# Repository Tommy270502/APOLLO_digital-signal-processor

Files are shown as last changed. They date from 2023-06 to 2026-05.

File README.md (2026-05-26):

# APOLLO Digital Signal Processor

APOLLO is a USB-powered STM32F401 digital signal-processing board and firmware
case study. The repository combines KiCad hardware design, STM32CubeIDE
firmware, external analog and memory devices, host-side tests for reusable C
logic, and validation notes for hardware-dependent behavior.

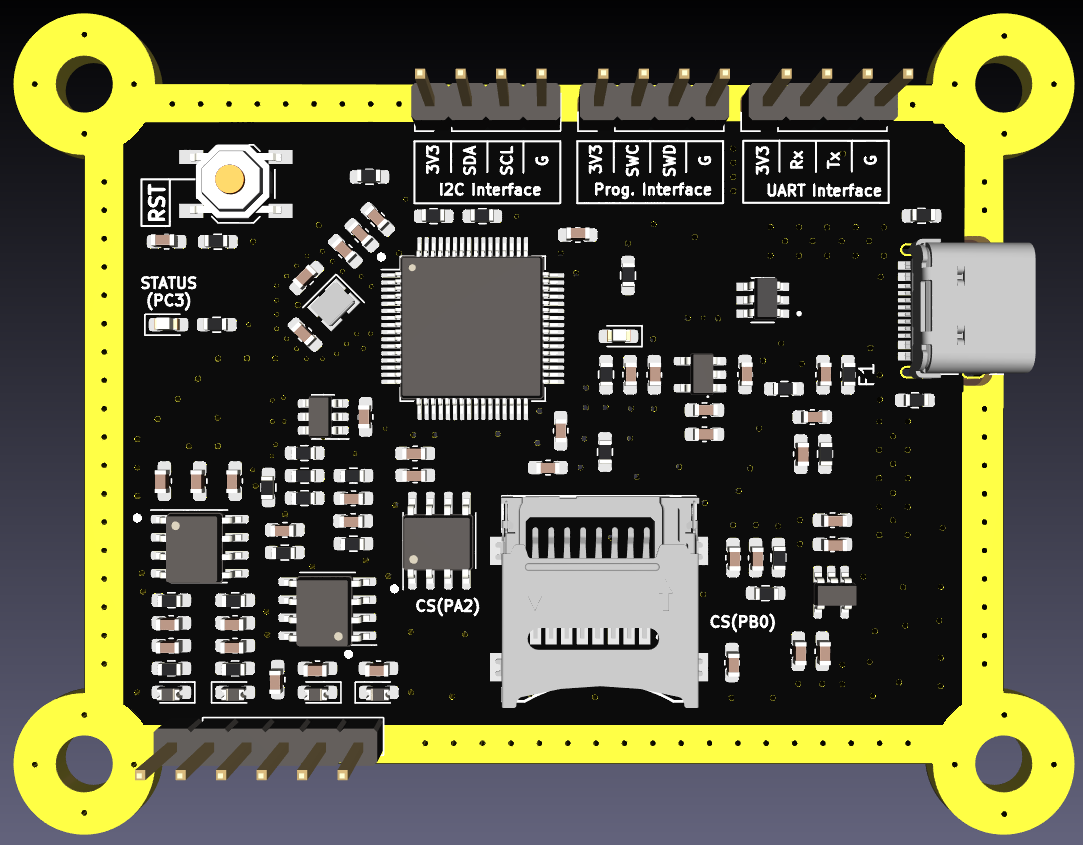
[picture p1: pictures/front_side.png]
APOLLO front side

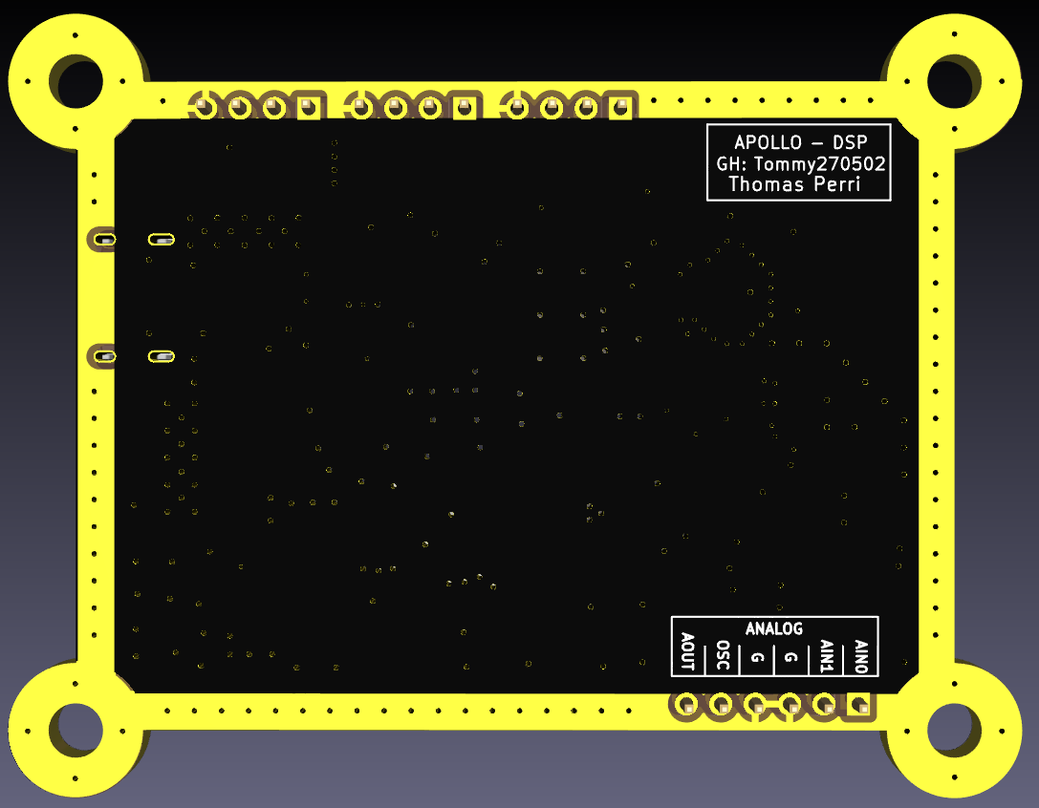
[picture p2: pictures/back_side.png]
APOLLO back side


## What This Demonstrates

- STM32F401 firmware architecture with CubeMX-generated code kept separate from
  hand-written application logic.
- USB CDC command and telemetry interface for live DSP configuration.
- Two-channel analog input support, external I2C DAC output, and SPI SRAM
  circular sample logging.
- Embedded-friendly DSP filters with fixed buffers and parameter validation.
- Clear distinction between implemented, host-tested, and hardware-validation
  required features.

## System Overview

```mermaid
flowchart LR
    Host["PC serial monitor"] <-- "USB CDC" --> USB["USB-C + ESD"]
    USB --> MCU["STM32F401RBTx\n84 MHz Cortex-M4F"]
    AIN["AIN0 / AIN1"] --> Analog["MCP602 analog conditioning"]
    Analog --> ADC["ADC1 CH0 / CH1"]
    ADC --> MCU
    MCU -- "I2C1 PB6/PB7" --> DAC["MCP4725-family\n12-bit I2C DAC"]
    DAC --> AOUT["Analog output"]
    MCU -- "SPI1 PA5/PA6/PA7" --> SRAM["23K256\n32 KiB SPI SRAM"]
    MCU -- "SPI1 + SD_nCS" --> SD["microSD socket\nfirmware unsupported"]
    MCU --> SWD["SWD debug"]
    MCU --> UART["USART1 header"]
```

## Firmware Architecture

```mermaid
flowchart TD
    Main["main.c\nHAL + CubeMX init"] --> App["app/apollo_app"]
    App --> ADC["platform/apollo_adc\nbounded polling"]
    App --> USB["platform/apollo_usb_cdc\nRX line buffer + TX wrapper"]
    App --> Chain["app/apollo_signal_chain"]
    Chain --> DSP["dsp/dsp_filters"]
    App --> DAC["drivers/dac_driver"]
    App --> Store["app/apollo_storage"]
    Store --> SRAM["drivers/sram_23k256"]
    App --> Tel["app/apollo_telemetry"]
    App --> Diag["app/apollo_diagnostics"]
    App --> CLI["app/apollo_cli"]
```

`main.c` now performs HAL initialization, CubeMX peripheral initialization, and
then calls `apollo_app_init()` and `apollo_app_task()`. Application behavior is
kept under `Software/Apollo - DSP/Core/Inc/*` and
`Software/Apollo - DSP/Core/Src/*`.

## Signal Pipeline

```mermaid
flowchart LR
    Source{"Source"} -->|ADC CH0/CH1| Raw["raw ADC"]
    Source -->|demo mode| Raw
    Raw --> Cal["offset/gain calibration"]
    Cal --> Filter["runtime DSP filter"]
    Filter --> Clamp["DAC saturation handling"]
    Clamp --> DAC["I2C DAC write"]
    Filter --> Telemetry["USB CDC telemetry"]
    Clamp --> Log["SPI SRAM circular log"]
    Raw --> Diagnostics["min/max/mean/errors"]
```

Default firmware behavior preserves the original demo path: ADC channel 0 is
sampled, a 1 kHz first-order low-pass filter is applied, the result is written
to the external DAC, telemetry is streamed over USB CDC, and compact sample
records are written to external SRAM when the SRAM self-test passes.

## USB Commands

Commands are sent over the USB CDC virtual COM port with newline termination.

| Command | Purpose |
| --- | --- |
| `help` | Print command summary. |
| `status` | Print sample count, channel, filter, demo, calibration, storage, and error counters. |
| `filter bypass` | Disable filtering. |
| `filter lowpass <hz>` | First-order low-pass IIR. |
| `filter highpass <hz>` | First-order high-pass IIR. |
| `filter ema <alpha>` | Exponential moving average, `0 < alpha <= 1`. |
| `filter average <n>` | Moving average, up to 16 samples. |
| `filter median <n>` | Median filter, up to 9 samples. |
| `input 0` / `input 1` | Select ADC channel 0 or 1. |
| `demo off\|sine\|step\|impulse` | Use real ADC input or synthetic samples. |
| `telemetry on\|off` | Enable or disable periodic telemetry frames. |
| `calibrate clear` | Restore unity ADC/DAC scaling. |
| `calibrate adc <gain> <offset>` | Set ADC input calibration (gain 0.01-100, offset +/-4095). |
| `calibrate dac <gain> <offset>` | Set DAC output calibration (gain 0.01-100, offset +/-4095). |

## Telemetry

Sample frames use this CSV format:

```text
T,timestamp_ms,sequence,channel,raw_adc,filtered,dac_code,filter,flags
```

Example:

```text
T,1200,57,0,1820,1784.42,1784,lowpass,0x00000000
```

Flags report clipping, demo source, filter errors, ADC errors, DAC errors, and
SRAM logging errors.

## Repository Layout

| Path | Purpose |
| --- | --- |
| `Apollo - DSP.kicad_pro` | Main KiCad project. |
| `Apollo - DSP.kicad_sch`, `Analog.kicad_sch`, `DSP.kicad_sch` | Hardware schematics. |
| `Apollo - DSP.kicad_pcb` | PCB layout. |
| `Gerber/` | Fabrication outputs. |
| `pictures/` | Board images. |
| `datasheets/` | Local component datasheets. |
| `Software/Apollo - DSP/` | STM32CubeIDE firmware project. |
| `tests/host/` | Host-buildable tests for pure C logic. |
| `docs/` | Technical documentation and validation notes. |

See [REPOSITORY_STRUCTURE.md](REPOSITORY_STRUCTURE.md) for more detail.

## Build And Flash

1. Open STM32CubeIDE.
2. Import `Software/Apollo - DSP/` as an existing STM32CubeIDE project.
3. Build the Debug or Release configuration.
4. Flash/debug over the SWD header using an ST-LINK compatible probe.
5. Open the USB CDC virtual COM port with a serial terminal.
6. Send `help`, `status`, or `demo sine` to verify the command path.

Generated `Debug/` and `Release/` folders are intentionally not tracked.
STM32CubeIDE regenerates them locally.

## Host Tests

Host tests cover pure logic that does not require STM32 HAL or board hardware:

```sh
make -C tests/host test
```

The tests exercise DSP filter behavior, command parsing, telemetry formatting,
diagnostics, calibration/clipping math, and signal-chain demo paths.

## Validation Status

- Host tests pass on Windows 11 / MSYS2 / GCC 15.2.0 (2026-05-27).
- Firmware Debug and Release builds pass with 0 errors (STM32CubeIDE 2.0.0,
  arm-none-eabi-gcc 14.3.1, 2026-05-27).
- Hardware-dependent behavior requires board validation:
  ADC channel accuracy, DAC output voltage, SRAM SPI timing, and USB behavior
  under sustained traffic.
- microSD hardware is present, but firmware support is explicitly unsupported
  until a real SPI block-device and filesystem implementation is added.

See [docs/validation.md](docs/validation.md) for the full validation checklist.

## Engineering Highlights

- CubeMX-generated code is preserved and hand-written application code is moved
  into reviewable modules.
- Peripheral failures no longer force infinite retry loops in application code.
- Runtime filter selection and demo sources make the board demonstrable without
  external analog equipment.
- Documentation states validation limits instead of claiming untested hardware
  support.

## Future Work

- Move ADC acquisition to timer-triggered DMA with overrun accounting.
- Add real microSD support using a validated SPI block-device layer and FatFs.
- Add fixture-based hardware tests for DAC linearity, ADC channel calibration,
  SRAM retention, and USB throughput.
- Add optional firmware CI if a reproducible STM32 toolchain image is adopted.

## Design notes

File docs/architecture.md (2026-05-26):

# Architecture

APOLLO separates generated STM32CubeIDE infrastructure from hand-written
application firmware. CubeMX owns peripheral setup in `main.c`, MSP files, USB
device glue, HAL, CMSIS, and middleware. Application code lives below
`Core/Inc/app`, `Core/Inc/dsp`, `Core/Inc/drivers`, and `Core/Inc/platform`
with matching source folders.

```mermaid
flowchart TD
    Main["CubeMX main.c"] --> App["apollo_app"]
    App --> Platform["platform\nADC + USB CDC helpers"]
    App --> Signal["signal chain"]
    Signal --> DSP["DSP filters"]
    App --> Drivers["DAC + SRAM + SD status drivers"]
    App --> Telemetry["telemetry formatter"]
    App --> Diagnostics["diagnostics counters"]
    App --> CLI["command parser"]
```

The main runtime path is tick scheduled. ADC polling is still used in this
cleanup pass, but it is bounded and isolated in `platform/apollo_adc.c` so a
future timer/DMA implementation can replace it without rewriting the signal
chain.

## Data Flow

```mermaid
flowchart LR
    ADC["ADC or demo source"] --> Process["calibrate + filter"]
    Process --> DAC["DAC code clamp"]
    DAC --> I2C["I2C DAC write"]
    Process --> USB["CSV telemetry"]
    DAC --> SRAM["8-byte SRAM record"]
    Process --> Diag["diagnostics"]
```

The SRAM record format is little-endian:

| Offset | Type | Field |
| --- | --- | --- |
| 0 | `uint32_t` | timestamp in milliseconds |
| 4 | `uint16_t` | raw ADC code |
| 6 | `uint16_t` | DAC code |

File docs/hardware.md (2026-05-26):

# Hardware

APOLLO is a USB-powered STM32F401RBTx board with analog input/output circuitry,
external SRAM, USB CDC connectivity, and debug headers.

## Main Blocks

- STM32F401RBTx MCU running from an HSE-based 84 MHz clock configuration.
- USB-C connector with USB OTG FS routed to PA11/PA12.
- Two analog input labels, `AIN0` and `AIN1`, routed through analog conditioning
  to ADC channel nets.
- MCP4725-family external I2C DAC on I2C1.
- 23K256 32 KiB SPI SRAM on SPI1.
- microSD socket sharing the SPI bus through a separate chip-select net.
- SWD and USART1 headers for programming, debug, and expansion.

## DAC Naming

The schematic uses an MCP4725-family KiCad symbol. The firmware now uses a
neutral `dac_driver` name and documents the driver as MCP4725-family compatible
instead of naming the source files after MCP4726.

## SD-Card Status

The microSD socket is present in hardware. Firmware support is intentionally
reported as unsupported until an SPI block-device layer, card initialization,
and filesystem integration are implemented and validated.

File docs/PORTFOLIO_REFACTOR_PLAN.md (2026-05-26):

# APOLLO Portfolio Refactor Plan

## Summary

This plan turns APOLLO from a functional project archive into a public embedded
engineering case study. The work is split into small phases so each change can
be reviewed independently and validated at the right level.

## Phase 1: Repository Hygiene

- Remove tracked generated artifacts and local state:
  - STM32CubeIDE workspace metadata in `Software/.metadata/`
  - Generated firmware build outputs in `Software/Apollo - DSP/Debug/` and
    `Software/Apollo - DSP/Release/`
  - KiCad lock/cache/local files and automatic backup ZIPs
  - Packaged ZIP snapshots
  - Broken or unsupported local artifacts such as the orphaned KiCad plugin
    gitlink and stale unused flash header
- Keep source assets needed to understand, build, fabricate, or validate the
  project:
  - KiCad schematics, PCB, project files, Gerbers, board pictures, datasheets
  - STM32CubeIDE project files, CubeMX `.ioc`, linker script, startup, HAL,
    CMSIS, USB middleware, and hand-written firmware source
- Strengthen `.gitignore` for STM32CubeIDE, KiCad, generated binaries,
  archives, temporary files, and local metadata.
- Add a short repository structure document.

## Phase 2: Firmware Architecture Cleanup

- Keep CubeMX generated code boundaries intact.
- Add clear hand-written firmware folders:
  - `Core/Inc/app` and `Core/Src/app`
  - `Core/Inc/dsp` and `Core/Src/dsp`
  - `Core/Inc/drivers` and `Core/Src/drivers`
  - `Core/Inc/platform` and `Core/Src/platform`
- Refactor `main.c` so it mainly performs HAL setup, CubeMX peripheral setup,
  application initialization, and the application run loop.
- Move application behavior into focused modules for configuration, signal
  processing, telemetry, diagnostics, storage, and platform access.

## Phase 3: DSP Feature Enhancement

- Replace the minimal filter module with a reusable embedded DSP filter library.
- Implement fixed-size, no-allocation filters:
  - bypass
  - first-order low-pass IIR
  - first-order high-pass IIR
  - exponential moving average
  - moving average
  - small-window median
- Validate parameters and expose reset/init/update APIs.
- Add a minimal command parser for runtime filter selection where practical.

## Phase 4: Signal-Chain Improvements

- Preserve the current default behavior while making the signal chain explicit.
- Add active ADC channel selection between the two wired analog inputs.
- Add calibration, clipping/saturation flags, diagnostics, and a synthetic demo
  source.
- Expand telemetry to include timestamp, sequence, channel, raw ADC, filtered
  value, DAC code, filter mode, and flags.
- Document SRAM circular logging format.

## Phase 5: ADC and Timing Review

- Isolate ADC acquisition behind a platform module.
- Replace unbounded ADC waits and delay-driven timing with bounded polling and
  tick-based scheduling in this cleanup pass.
- Document timer/DMA sampling as a future upgrade unless it is implemented and
  hardware-validated later.

## Phase 6: Driver Cleanup

- Improve external SRAM and DAC APIs with status returns and input validation.
- Rename or document the external DAC driver using neutral MCP4725-family
  naming.
- Keep USB CDC telemetry nonblocking where possible and account for busy states.
- Replace SD-card no-op stubs with an honest unsupported status.

## Phase 7: Tests and Host-Side Validation

- Add a lightweight host-buildable C test runner.
- Cover DSP filters, command parsing, telemetry formatting, calibration math,
  and circular-buffer indexing.
- Use plain `gcc` and `make` instead of a heavy test framework.

## Phase 8: Documentation

- Upgrade README into a concise public case study.
- Add focused technical docs:
  - architecture
  - firmware
  - DSP filters
  - demo usage
  - hardware
  - testing
  - validation
  - future work
- Use Mermaid diagrams for architecture, data flow, and state-machine views.

## Phase 9: CI and Automation

- Add GitHub Actions for host-side tests and lightweight documentation/repo
  sanity checks.
- Document manual STM32CubeIDE build and flash steps instead of pretending
  firmware CI exists if the embedded toolchain is not installed in CI.

## Phase 10: Portfolio Polish

- Add engineering highlights, design tradeoffs, validation limits, and future
  work sections.
- Make the final repository credible to embedded hardware, firmware, and
  systems-integration reviewers.

## Validation Strategy

- Use narrow checks first:
  - `git status --short`
  - tracked-file audits for generated artifacts
  - host tests once added
  - local firmware build if the STM32 toolchain is available
- Document hardware-only validation steps when hardware cannot be exercised
  directly.

## Assumptions

- Hardware validation is not available during this cleanup pass.
- CubeMX regeneration safety is more important than aggressive code movement.
- Unsupported hardware functions should be documented honestly rather than
  represented as working firmware features.

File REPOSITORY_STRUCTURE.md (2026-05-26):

# Repository Structure

APOLLO is organized so hardware design assets, firmware source, validation
material, and public documentation are easy to inspect independently.

| Path | Purpose |
| --- | --- |
| `Apollo - DSP.kicad_pro` | Main KiCad project file. |
| `Apollo - DSP.kicad_sch` | Top-level schematic. |
| `Analog.kicad_sch` | Analog input/output and external DAC circuitry. |
| `DSP.kicad_sch` | STM32F401, USB, memory, SD-card socket, SWD, and UART circuitry. |
| `Apollo - DSP.kicad_pcb` | Routed PCB layout. |
| `Gerber/` | Fabrication outputs and drill files. |
| `pictures/` | Board images used by the public documentation. |
| `datasheets/` | Local component datasheets and reference material. |
| `Software/Apollo - DSP/` | STM32CubeIDE firmware project. |
| `Software/Apollo - DSP/Core/` | Firmware startup, generated HAL hooks, and application source. |
| `Software/Apollo - DSP/Core/Inc/app` | Application interfaces, command parser, signal chain, telemetry, diagnostics, and storage APIs. |
| `Software/Apollo - DSP/Core/Inc/dsp` | Reusable DSP filter interfaces. |
| `Software/Apollo - DSP/Core/Inc/drivers` | Board-level DAC, SRAM, and SD-card status drivers. |
| `Software/Apollo - DSP/Core/Inc/platform` | HAL-facing acquisition and USB CDC helpers. |
| `Software/Apollo - DSP/Drivers/` | STM32 HAL and CMSIS driver sources generated/copied by CubeMX. |
| `Software/Apollo - DSP/Middlewares/` | STM32 USB Device middleware. |
| `Software/Apollo - DSP/USB_DEVICE/` | CubeMX USB CDC device glue code. |
| `tests/host/` | Host-buildable tests for pure firmware logic. |
| `docs/` | Portfolio plan and technical documentation. |

Generated build outputs, IDE workspaces, KiCad lock/cache files, and packaged
snapshots are intentionally ignored and should be regenerated locally as needed.

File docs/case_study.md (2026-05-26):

# Case Study: APOLLO Digital Signal Processor

APOLLO demonstrates the full path from custom embedded hardware design to
structured firmware and validation planning. The board combines analog
front-end circuitry, an STM32F401 microcontroller, USB CDC communication, an
external I2C DAC, SPI SRAM, and a microSD hardware footprint.

The firmware refactor focuses on maintainability and honesty. Generated CubeMX
code remains isolated, application behavior is moved into small modules, and
hardware-dependent limitations are called out directly. The result is a public
repository that shows embedded firmware architecture, board-level driver design,
DSP implementation, documentation discipline, and practical validation thinking.

## Design Tradeoffs

- Polling ADC acquisition is retained for this cleanup pass to avoid unverified
  timing changes. The code now isolates acquisition so DMA can be introduced
  later.
- The DSP filters use fixed buffers instead of dynamic allocation to keep memory
  use deterministic.
- microSD support is reported as unsupported rather than represented by no-op
  placeholder functions.
- The DAC driver is named for the board-level function instead of a specific
  MCP472x variant because the schematic uses an MCP4725-family symbol.

## Client-Relevant Signals

- Ability to clean and structure a mixed hardware/firmware repository.
- Practical STM32 HAL and CubeMX boundary management.
- Embedded C design with bounded buffers and explicit status codes.
- Validation planning that distinguishes host tests from hardware tests.

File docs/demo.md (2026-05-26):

# Demo

Connect the board over USB and open the CDC serial port. Line endings should
include `\n` or `\r\n`.

Useful commands:

```text
help
status
demo sine
filter lowpass 100
filter median 5
input 1
telemetry off
telemetry on
```

Telemetry frames:

```text
T,timestamp_ms,sequence,channel,raw_adc,filtered,dac_code,filter,flags
```

Demo modes generate synthetic ADC samples in firmware:

| Mode | Behavior |
| --- | --- |
| `demo sine` | 32-point sine-like waveform. |
| `demo step` | Alternates between low and high levels. |
| `demo impulse` | Single full-scale pulse every 64 samples. |
| `demo off` | Uses the selected ADC input. |

These modes make the firmware demonstrable without external analog signal
equipment. DAC and SRAM behavior still require hardware validation.

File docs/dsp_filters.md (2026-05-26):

# DSP Filters

The DSP library in `dsp/dsp_filters` is designed for small embedded targets:
fixed-size buffers, no dynamic allocation, explicit parameter validation, and a
simple `init/reset/update` API.

| Mode | Command | Use case | Tradeoff |
| --- | --- | --- | --- |
| Bypass | `filter bypass` | Baseline raw signal path. | No noise reduction. |
| Low-pass IIR | `filter lowpass <hz>` | Smooth high-frequency noise. | Adds phase lag. |
| High-pass IIR | `filter highpass <hz>` | Remove DC or slow drift. | Step inputs decay toward zero. |
| EMA | `filter ema <alpha>` | Simple smoothing with direct coefficient control. | Alpha must be tuned manually. |
| Moving average | `filter average <n>` | Predictable finite-window smoothing. | More RAM and group delay as `n` grows. |
| Median | `filter median <n>` | Reject isolated spikes. | More CPU than averaging due to per-sample sorting. |

Maximum windows are 16 samples for moving average and 9 samples for median.
These limits keep RAM and CPU use bounded on the STM32F401.

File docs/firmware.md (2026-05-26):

# Firmware

The firmware targets an STM32F401RBTx and is maintained as an STM32CubeIDE
project in `Software/Apollo - DSP/`.

## Responsibilities

| Module | Responsibility |
| --- | --- |
| `app/apollo_app` | Runtime orchestration, scheduling, command execution, and error accounting. |
| `app/apollo_signal_chain` | Calibration, filtering, demo sources, DAC clipping, and sample frame creation. |
| `app/apollo_cli` | Minimal USB CDC command parser. |
| `app/apollo_telemetry` | CSV telemetry and status formatting. |
| `app/apollo_storage` | SRAM circular sample logging. |
| `dsp/dsp_filters` | Reusable fixed-buffer DSP filters. |
| `drivers/dac_driver` | MCP4725-family 12-bit I2C DAC writes. |
| `drivers/sram_23k256` | 23K256 SPI SRAM mode, test, read, and write operations. |
| `drivers/sd_card` | Explicit unsupported status for microSD firmware support. |
| `platform/apollo_adc` | Bounded ADC polling and channel selection. |
| `platform/apollo_usb_cdc` | USB CDC RX line buffering and TX status mapping. |

## Runtime Loop

```mermaid
stateDiagram-v2
    [*] --> Init
    Init --> Run
    Run --> Commands: USB line available
    Commands --> Run
    Run --> Sample: 1 ms tick elapsed
    Sample --> Output
    Output --> Telemetry: 20 ms tick elapsed
    Output --> Run
    Telemetry --> Run
```

## Current Timing Choice

The project still uses ADC polling rather than timer-triggered DMA. The polling
is bounded by `APOLLO_ADC_TIMEOUT_MS` and hidden behind `apollo_adc_read()`.
That preserves current behavior while making the future DMA migration localized.

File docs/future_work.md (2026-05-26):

# Future Work

- Replace polling ADC acquisition with timer-triggered DMA and explicit overrun
  accounting.
- Add a real microSD SPI block-device layer and FatFs integration.
- Add calibration commands for ADC offset/gain and DAC scaling with persisted
  calibration data if nonvolatile storage is added.
- Add hardware-in-the-loop tests for ADC channel accuracy, DAC linearity, SRAM
  logging, and USB CDC throughput.
- Add firmware CI using a pinned STM32 toolchain container if reproducible build
  time and maintenance cost are acceptable.

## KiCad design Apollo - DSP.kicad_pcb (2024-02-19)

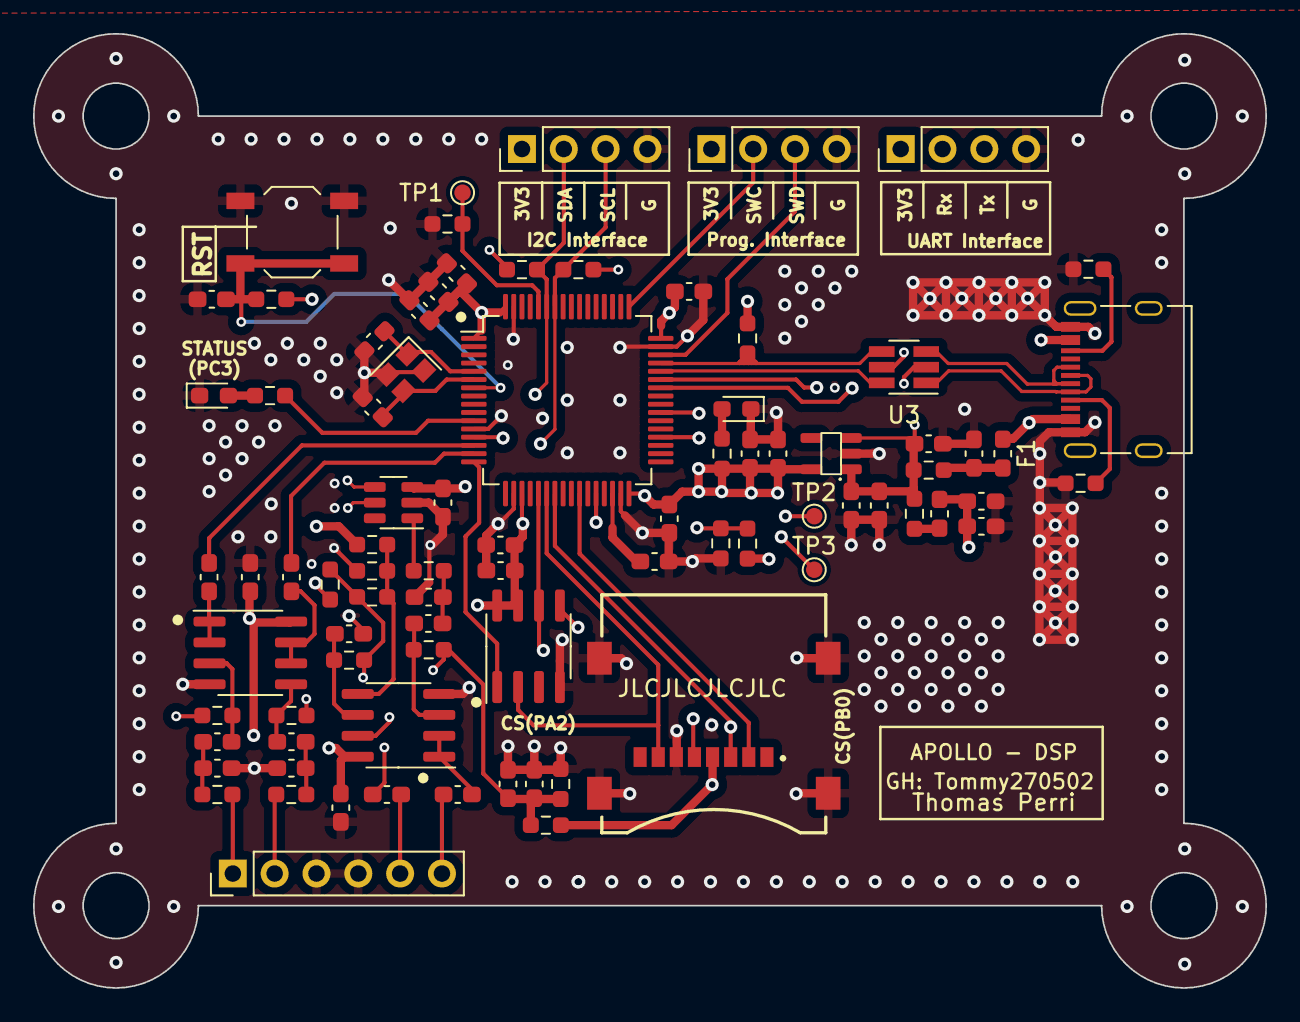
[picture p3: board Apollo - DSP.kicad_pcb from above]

Board: 4 copper layers, 74.9 x 58.0 mm, 83 parts (0 on the bottom side), 56 nets.

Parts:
C1, C2, C3, C5, C8, C13, C14, C20, C23: 10u; C_0603_1608Metric_Pad1.08x0.95mm_HandSolder
C4, C6, C15, C16, C17, C18, C19, C21, C26, C29, C30, C31, C32, C34, C36, C37, C39, C40, C41, C42: 100n; C_0603_1608Metric_Pad1.08x0.95mm_HandSolder
C7: 220u; C_0603_1608Metric_Pad1.08x0.95mm_HandSolder
C24, C25: 10p; C_0603_1608Metric_Pad1.08x0.95mm_HandSolder
C33, C35, C38: 1n; C_0603_1608Metric_Pad1.08x0.95mm_HandSolder
D1: Red; LED_0603_1608Metric_Pad1.05x0.95mm_HandSolder
D2: Green; LED_0603_1608Metric_Pad1.05x0.95mm_HandSolder
F1: 500mA; Fuse_0603_1608Metric_Pad1.05x0.95mm_HandSolder
FB1: 100R@100MHz; R_0603_1608Metric_Pad0.98x0.95mm_HandSolder
J1: USB_C_Receptacle_USB2.0; USB_C_Receptacle_Palconn_UTC16-G
J2, J3, J6: Conn_01x04; PinHeader_1x04_P2.54mm_Vertical
J4: MEM2067-02-180-00-A_REVB; GCT_MEM2067-02-180-00-A_REVB
J5: Conn_01x06; PinHeader_1x06_P2.54mm_Vertical
L1: 8u8; L_0603_1608Metric_Pad1.05x0.95mm_HandSolder
R1, R8: 1k; R_0603_1608Metric_Pad0.98x0.95mm_HandSolder
R2, R3: 5.1k; R_0603_1608Metric_Pad0.98x0.95mm_HandSolder
R4, R5, R9, R10, R16, R18, R19, R21: 5k1; R_0603_1608Metric_Pad0.98x0.95mm_HandSolder
R6, R7, R22, R23: 10k; R_0603_1608Metric_Pad0.98x0.95mm_HandSolder
R11, R12, R15: 1M; R_0603_1608Metric_Pad0.98x0.95mm_HandSolder
R13: 1.5k; R_0603_1608Metric_Pad0.98x0.95mm_HandSolder
R13#2, R14, R17, R20: 160R; R_0603_1608Metric_Pad0.98x0.95mm_HandSolder
R24: 10R; R_0603_1608Metric_Pad0.98x0.95mm_HandSolder
RESET1: RST; SW_SPST_TL3342
TP1, TP2, TP3: TestPoint; TestPoint_Pad_D1.0mm
U1: NCP115ASN330T2G
U3: USBLC6-2SC6; SOT-23-6_Handsoldering
U4: STM32F401RBTx; LQFP-64_10x10mm_P0.5mm
U5: 23K256; SOIC-8_3.9x4.9mm_P1.27mm
U6: MCP4725xxx-xCH; SOT-23-6
U7, U8: MCP602; SOIC-8_3.9x4.9mm_P1.27mm
Y1: 16MHz; Crystal_SMD_2520-4Pin_2.5x2.0mm

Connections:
3.3V: C5.1, C6.1, C15.1, C16.1, C17.1, C18.1, C19.1, C20.1, C26.1, C29.2, J2.1, J3.1, J4.4 (VDD), J6.1, R1.2, R4.2, R6.1, R9.2, R10.2, R13.1, R23.1, U1.5 (out), U4.1 (VBAT), U4.13 (VREF+), U4.19 (VDD), U4.32 (VDD), U4.48 (VDD), U4.64 (VDD), U5.7 (nHLD), U5.8 (VCC), U6.3 (VDD)
+5V: C2.1, C3.1, C4.1, FB1.2, R24.1, U1.1 (in), U1.3 (EN), U3.5
+5VA: C7.1, C8.1, C39.2, C42.2, L1.2, R21.1, U7.8 (V+), U8.8 (V+)
/Analog/CH0_+: C30.2, R11.1, U7.3 (+)
/Analog/CH0_LPF: C30.1, C33.2, R13#2.1
/Analog/CH0_OP_OUT: C32.1, U7.1, U7.2 (-)
/Analog/CH1_+: C36.2, R15.1, U7.5 (+)
/Analog/CH1_LPF: C36.1, C38.2, R17.1
/Analog/CH1_OP_OUT: C37.1, U7.6 (-), U7.7
/POW: F1.1, J1.A4 (VBUS), J1.A9 (VBUS), J1.B4 (VBUS), J1.B9 (VBUS)
ADC_CH0_IN: C32.2, U4.14 (PA0)
ADC_CH1_IN: C37.2, U4.15 (PA1)
AIN0: J5.1, R13#2.2
AIN1: J5.2, R17.2
AOUT: C34.2, J5.6
BOOT0: R7.1, TP1.1, U4.60 (BOOT0)
BOOT1: R22.1, R23.2, U4.28 (PB2)
DAC_OUT: R14.2, U6.1 (VOUT)
GND: C1.2, C2.2, C3.2, C4.2, C5.2, C6.2, C7.2, C8.2, C13.2, C14.2, C15.2, C16.2, C17.2, C18.2, C19.2, C20.2, C21.2, C23.2, C24.2, C25.2, C26.2, C29.1, C33.1, C35.1, C38.1, C39.1, C41.1, C42.1, D1.1 (K), D2.1 (K), J1.A1 (GND), J1.A12 (GND), J1.B1 (GND), J1.B12 (GND), J2.4, J3.4, J4.6 (VSS), J4.9 (SHIELD), J4.10 (SHIELD), J4.11 (SHIELD), J4.12 (SHIELD), J5.3, J5.4, J6.4, R2.2, R3.2, R5.2, R7.2, R18.2, R22.2, RESET1.1, U1.2 (GND), U3.2, U4.12 (VSSA), U4.18 (VSS), U4.31 (VSS), U4.47 (VSS), U4.63 (VSS), U5.4 (GND), U6.2 (VSS), U7.4 (V-), U8.4 (V-), Y1.2, Y1.4
MISO: J4.7 (DAT0), U4.22 (PA6), U5.2 (SO)
MOSI: J4.3 (CMD), U4.23 (PA7), U5.5 (SI)
NRST: C21.1, R6.2, RESET1.2, U4.7 (NRST)
unnamed: C31.1, C35.2, R14.1
unnamed: C40.1, R20.1
unnamed: D1.2 (A), R1.1
unnamed: D2.2 (A), R8.2
unnamed: J1.A5 (CC1), R2.1
unnamed: J1.B5 (CC2), R3.1
unnamed: L1.1, R24.2
unnamed: R16.1, R19.1, R20.2, U8.7
unnamed: TP3.1, U4.36 (PB15)
unnamed: R8.1, U4.11 (PC3)
unnamed: TP2.1, U4.39 (PC8)
unnamed: C23.1, U4.30 (VCAP1)
unnamed: C31.2, R12.1, U8.3 (+)
unnamed: C34.1, U8.1, U8.2 (-)
unnamed: R16.2, R18.1, R21.2, U8.5 (+)
unnamed: C41.2, R19.2, U8.6 (-)
OSC: C40.2, J5.5
RAM_nCS: U4.16 (PA2), U5.1 (nCS)
Rx: J3.2, U4.43 (PA10)
SCK: J4.5 (CLK), U4.21 (PA5), U5.6 (SCK)
SCL: J6.3, R9.1, U4.58 (PB6), U6.5 (SCL)
SDA: J6.2, R10.1, U4.59 (PB7), U6.4 (SDA)
SD_nCS: J4.2 (CD/DAT3), U4.26 (PB0)
SWCLK: J2.2, U4.49 (PA14)
SWDIO: J2.3, U4.46 (PA13)
Tx: J3.3, U4.42 (PA9)
USB_CONN_+: J1.A6 (D+), J1.B6 (D+), U3.3
USB_CONN_-: J1.A7 (D-), J1.B7 (D-), U3.1
USB_D+: R13.2, U3.4, U4.45 (PA12)
USB_D-: U3.6, U4.44 (PA11)
VAA: C13.1, C14.1, R4.1, R5.1, R11.2, R12.2, R15.2
VBUS: C1.1, F1.2, FB1.1
X1: C24.1, U4.5 (PH0), Y1.1
X2: C25.1, U4.6 (PH1), Y1.3

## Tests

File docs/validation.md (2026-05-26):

# Validation

## Host Test Results

| Date | Platform | Compiler | Result |
| --- | --- | --- | --- |
| 2026-05-27 | Windows 11 / MSYS2 | GCC 15.2.0 | All tests pass |

Run:

```sh
make -C tests/host test
```

Tests cover:
- DSP filters (lowpass, highpass, EMA, moving average, median)
- CLI command parsing (filter, input, demo, telemetry, calibrate)
- Calibration validation (gain bounds, offset bounds, signal-path math)
- Signal chain saturation and DAC clipping flags
- Diagnostics (sample counting, min/max/mean ADC)
- Telemetry formatting (sample and status frames)

## Firmware Build Results

| Date | Configuration | Compiler | Result | Size (text/data/bss) |
| --- | --- | --- | --- | --- |
| 2026-05-27 | Debug | arm-none-eabi-gcc 14.3.1 | 0 errors, 1 warning | 74,976 / 716 / 8,024 |
| 2026-05-27 | Release | arm-none-eabi-gcc 14.3.1 | 0 errors, 1 warning | 49,816 / 712 / 8,024 |

Built via STM32CubeIDE 2.0.0 headless builder. The single warning is a
standard bare-metal RWX LOAD segment note from the linker.

All new source directories (`Core/Src/app/`, `Core/Src/dsp/`,
`Core/Src/drivers/`, `Core/Src/platform/`) are discovered automatically
by the managed build via the `Core` source entry in `.cproject`.

## Board Smoke Validation (Phase 3)

Firmware builds verified. Hardware tests require physical board.

- [ ] USB CDC enumeration
- [ ] `help` command response
- [ ] `status` command response
- [ ] Malformed command error handling
- [ ] `demo sine`, `demo step`, `demo impulse`
- [ ] `filter bypass`, `filter lowpass 100`, `filter highpass 100`
- [ ] `filter average 5`, `filter median 5`
- [ ] Telemetry frame format over USB CDC
- [ ] `input 0` and `input 1` ADC readings
- [ ] Known voltage readings on both channels
- [ ] DAC follows filtered/demo signal
- [ ] SRAM self-test status
- [ ] No increasing SRAM error count during normal logging

## Phase Status

| Phase | Status | Notes |
| --- | --- | --- |
| 1. Stabilize refactor | Done | Commits split and tracked |
| 2. Host tests / CI | Done | Tests pass on Windows; CI not yet run |
| 3. Board smoke | Partial | Firmware builds; hardware tests require physical board |
| 4. USB/app robustness | Done | RX overflow counter, startup reporting |
| 5. Calibration | Done | calibrate adc/dac commands with validation |
| 6. ADC timer/DMA | Done | DMA compile-time option, polling default, both build verified |
| 7. microSD | Unsupported | Documented as future work |
| 8. README | Partial | Updated after host test verification |

## Known Limits

- ADC uses bounded polling, not timer-triggered DMA.
- microSD firmware support is not implemented.
- Hardware behavior must be validated on the actual board.
- GitHub CI has not been triggered yet (not pushed to remote).
- Phase 3 hardware smoke requires physical board access.
- Phase 6 DMA runtime behavior (sample rate stability, overrun count) requires
  board validation. Enable with `-DAPOLLO_ADC_USE_DMA=1` compiler define.

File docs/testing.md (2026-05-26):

# Testing

Host-side tests live in `tests/host` and exercise logic that does not depend on
STM32 HAL or board hardware.

```sh
make -C tests/host test
```

Covered areas:

- low-pass step response
- high-pass step decay
- moving average circular window behavior
- median outlier rejection
- filter parameter validation
- USB command parsing
- telemetry formatting
- diagnostics mean/min/max accounting
- signal-chain DAC clipping flags

The firmware build remains an STM32CubeIDE workflow because generated build
directories are not tracked.

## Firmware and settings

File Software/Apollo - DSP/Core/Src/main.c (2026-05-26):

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
/* Includes ------------------------------------------------------------------*/
#include "main.h"
#include "usb_device.h"

/* USER CODE BEGIN Includes */
#include "app/apollo_app.h"
#include "drivers/sram_23k256.h"
/* USER CODE END Includes */

ADC_HandleTypeDef hadc1;
DMA_HandleTypeDef hdma_adc1;

I2C_HandleTypeDef hi2c1;

SPI_HandleTypeDef hspi1;

UART_HandleTypeDef huart1;

/* USER CODE BEGIN PV */
static apollo_app_t apollo_app;
/* USER CODE END PV */

void SystemClock_Config(void);
static void MX_GPIO_Init(void);
static void MX_DMA_Init(void);
static void MX_ADC1_Init(void);
static void MX_I2C1_Init(void);
static void MX_SPI1_Init(void);
static void MX_USART1_UART_Init(void);
/**
  * @brief  The application entry point.
  * @retval int
  */
int main(void)
{
  /* USER CODE BEGIN 1 */
	apollo_app_handles_t apollo_handles;
  /* USER CODE END 1 */

  /* MCU Configuration--------------------------------------------------------*/

  /* Reset of all peripherals, Initializes the Flash interface and the Systick. */
  HAL_Init();

  /* Configure the system clock */
  SystemClock_Config();

  /* Initialize all configured peripherals */
  MX_GPIO_Init();
  MX_DMA_Init();
  MX_ADC1_Init();
  MX_I2C1_Init();
  MX_SPI1_Init();
  MX_USART1_UART_Init();
  MX_USB_DEVICE_Init();
  /* USER CODE BEGIN 2 */
  apollo_handles.adc = &hadc1;
  apollo_handles.dac_i2c = &hi2c1;
  apollo_handles.sram_spi = &hspi1;
  apollo_handles.uart = &huart1;
  (void)apollo_app_init(&apollo_app, &apollo_handles);
  /* USER CODE END 2 */

  /* Infinite loop */
  /* USER CODE BEGIN WHILE */
  while (1)
  {
    /* USER CODE END WHILE */

    /* USER CODE BEGIN 3 */
	apollo_app_task(&apollo_app);
  }
  /* USER CODE END 3 */
}

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


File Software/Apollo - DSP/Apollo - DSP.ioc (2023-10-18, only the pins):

Mcu.UserName=STM32F401RBTx
PA0-WKUP.Signal=ADCx_IN0
PA1.Signal=ADCx_IN1
PA10.Signal=USART1_RX
PA11.Signal=USB_OTG_FS_DM
PA12.Signal=USB_OTG_FS_DP
PA13.Signal=SYS_JTMS-SWDIO
PA14.Signal=SYS_JTCK-SWCLK
PA5.Signal=SPI1_SCK
PA6.Signal=SPI1_MISO
PA7.Signal=SPI1_MOSI
PA9.Signal=USART1_TX
PB6.Signal=I2C1_SCL
PB7.Signal=I2C1_SDA

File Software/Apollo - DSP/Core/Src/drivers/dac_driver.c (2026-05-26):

#include "drivers/dac_driver.h"

#include <stddef.h>

apollo_status_t dac_driver_init(dac_driver_t *driver,
								I2C_HandleTypeDef *i2c,
								uint8_t address_7bit,
								uint32_t timeout_ms) {
	if (driver == NULL || i2c == NULL) {
		return APOLLO_STATUS_INVALID_ARG;
	}

	driver->i2c = i2c;
	driver->address = (uint16_t)(address_7bit << 1U);
	driver->timeout_ms = timeout_ms;

	return dac_driver_write(driver, 0U);
}

apollo_status_t dac_driver_write(dac_driver_t *driver, uint16_t code) {
	uint16_t dac_code;
	uint8_t tx_data[2];

	if (driver == NULL || driver->i2c == NULL) {
		return APOLLO_STATUS_INVALID_ARG;
	}

	dac_code = code;
	if (dac_code > DAC_DRIVER_MAX_CODE) {
		dac_code = DAC_DRIVER_MAX_CODE;
	}

	/* MCP4725-family fast-mode 12-bit write: command/power bits plus D11..D8, then D7..D0. */
	tx_data[0] = (uint8_t)((dac_code >> 8) & 0x0FU);
	tx_data[1] = (uint8_t)(dac_code & 0xFFU);

	if (HAL_I2C_Master_Transmit(driver->i2c,
								driver->address,
								tx_data,
								(uint16_t)sizeof(tx_data),
								driver->timeout_ms) != HAL_OK) {
		return APOLLO_STATUS_HAL_ERROR;
	}

	return APOLLO_STATUS_OK;
}

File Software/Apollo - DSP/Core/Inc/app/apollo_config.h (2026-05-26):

#ifndef APP_APOLLO_CONFIG_H_
#define APP_APOLLO_CONFIG_H_

#include <stdint.h>

#define APOLLO_ADC_MAX_CODE                 4095U
#define APOLLO_DAC_MAX_CODE                 4095U

#define APOLLO_DEFAULT_SAMPLE_PERIOD_MS     1U
#define APOLLO_DEFAULT_SAMPLE_PERIOD_S      0.001f
#define APOLLO_DEFAULT_FILTER_CUTOFF_HZ     1000.0f
#define APOLLO_USB_TELEMETRY_PERIOD_MS      20U

#define APOLLO_ADC_TIMEOUT_MS               2U
#define APOLLO_I2C_TIMEOUT_MS               20U
#define APOLLO_SPI_TIMEOUT_MS               20U

#define APOLLO_CLI_LINE_LENGTH              96U
#define APOLLO_TELEMETRY_LINE_LENGTH        320U

#define APOLLO_SRAM_LOG_RECORD_BYTES        8U

#endif /* APP_APOLLO_CONFIG_H_ */

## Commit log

2023-01-27 added a pinheader for analog signal in
    [Analog.kicad_sch, Apollo - DSP.kicad_pcb, Apollo - DSP.kicad_sch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]
2023-01-27 Added polygons
    [Analog.kicad_sch, Apollo - DSP.kicad_sch, DSP.kicad_sch]
2023-02-03 had to change mcu since the stm32f103 does not have an FPU -> too slow for DSP applications
    [Apollo - DSP-B_Cu.gbr, Apollo - DSP-B_Mask.gbr, Apollo - DSP-B_Paste.gbr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]
2023-02-03 completed schematic and layout with new mcu, also added an SPI connector
    [Analog.kicad_sch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]
2023-02-03 forgot the cs pins
    [DSP.kicad_sch]
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2023-02-04 moved decoupling caps closer to dsp
    [Analog.kicad_sch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]
2023-02-04 added more silkscreen lables
    [Apollo - DSP.kicad_pcb, DSP.kicad_sch]
2023-02-04 added some relevant datasheets
    [Analog.kicad_sch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]
2023-02-05 wrote some code to read out an adc input filter it and send it out through usb
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2023-02-16 trying to generate bom with kibom
    [Apollo - DSP-B_Cu.gbr, Apollo - DSP-B_Mask.gbr, Apollo - DSP-B_Paste.gbr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]
2023-02-16 changed footprint of caps
    [Analog.kicad_sch, Apollo - DSP.kicad_sch, DSP.kicad_sch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]
2023-02-18 grounded mounting holes gnd top layer polygon and cool looking gnd strips on analog side
    [Analog.kicad_sch, Apollo - DSP.kicad_sch, DSP.kicad_sch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]
2023-02-18 minor modifications with refs and new pictures
    [Apollo - DSP-B_Cu.gbr, Apollo - DSP-B_Mask.gbr, Apollo - DSP-B_Paste.gbr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]
2023-02-18 fixed mounting hole size from 6mm diam to 3mm diam
    [Apollo - DSP.kicad_pcb]
2023-02-18 own foorprint for LDO
    [Apollo - DSP.kicad_pcb, Apollo - DSP.kicad_sch]
2023-02-18 generated gerber files
    [Apollo - DSP-B_Cu.gbr, Apollo - DSP-B_Mask.gbr, Apollo - DSP-B_Paste.gbr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]
2023-02-18 replaced 741 opamp for lm358 due to cost reasons
    [Analog.kicad_sch, Apollo - DSP.kicad_pcb, Apollo - DSP.kicad_sch]
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2023-02-18 added 3d model and updated pics
    [Apollo - DSP.kicad_pcb, Apollo - DSP.kicad_sch]
2023-02-18 added jlcpcb ordernumber location
    [Apollo - DSP-B_Cu.gbr, Apollo - DSP-B_Mask.gbr, Apollo - DSP-B_Paste.gbr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]
2023-02-18 regenerated gerbers
    [Apollo - DSP-B_Cu.gbr, Apollo - DSP-B_Mask.gbr, Apollo - DSP-B_Paste.gbr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]
2023-02-24 tiedied usb differential pair routing
    [Apollo - DSP.kicad_pcb]
2023-02-24 new gerber
    [Apollo - DSP-B_Cu.gbr, Apollo - DSP-B_Mask.gbr, Apollo - DSP-B_Paste.gbr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]
2023-03-29 added boot and reset button
    [Analog.kicad_sch, Apollo - DSP.cfg, Apollo - DSP.kicad_pcb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]
2023-03-29 fixed usb differential routing -> no vias
    [Apollo - DSP.kicad_pcb, Apollo - DSP.kicad_sch]
2023-03-29 added 3d model for sd card
    [Apollo - DSP.kicad_pcb]
2023-04-12 smaller pcb removed ram unneccessary
    [Apollo - DSP.kicad_pcb, Apollo - DSP.kicad_sch, DSP.kicad_sch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]
2023-04-12 smaller mounting holes improved usb routing
    [Apollo - DSP.kicad_pcb, Apollo - DSP.kicad_sch, DSP.kicad_sch]
2023-04-13 removed solver mask from mounting holes and grounded it
    [Apollo - DSP.kicad_pcb]
2023-04-13 added pcb edge vias and grounded them (basically just esthethically pleasing but certaintly helps to shield analog side)
    [Apollo - DSP.kicad_pcb]
2023-04-14 start organising connectors
    [Apollo - DSP.kicad_pcb]
2023-04-14 added feature in the Lowpass init function to make sure the cutoff frequency is at least two times than the sample frequency
2023-05-02 fancy copper on edges
    [Apollo - DSP.kicad_pcb]
2023-05-07 moved analog power farther away from digital Power, removed SPI and I2C Interface since it was not needed in the V1
    [Apollo - DSP.kicad_pcb, DSP.kicad_sch]
2023-05-07 cleaned up the whole board
    [Analog.kicad_sch, Apollo - DSP.kicad_pcb, Apollo - DSP.kicad_sch]
2023-05-09 made analog circuitry a bit more compact moved whole board
    [Analog.kicad_sch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]
2023-05-15 added sram chip again, might come in handy for mor complex calculations
    [Analog.kicad_sch, Apollo - DSP.kicad_pcb, DSP.kicad_sch]
2023-05-18 updated pics
    [Analog.kicad_sch, Apollo - DSP.kicad_pcb, DSP.kicad_sch]
2023-05-18 added DAC and an onboard fixed oscilltor to quickly test the DSP
    [Analog.kicad_sch, Apollo - DSP.kicad_pcb, Apollo - DSP.kicad_sch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]
2023-05-18 silkscreen stuff
    [Apollo - DSP.kicad_pcb]
2023-05-22 added teardrops to increase yield&quality, also tuned usb data line skew
    [Apollo - DSP-B_Cu.gbr, Apollo - DSP-B_Mask.gbr, Apollo - DSP-B_Paste.gbr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]
2023-05-22 repoured polygons
    [Apollo - DSP.kicad_pcb]
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2023-05-26 implementing test ram function
    [Analog.kicad_sch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]
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2023-05-30 completed driver code for DAC, ready for testing when PCBs are assembled
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2023-06-07 fixed bootloader setting to SWD, removed boot button.
    [Apollo - DSP.kicad_pcb, DSP.kicad_sch]
2023-08-31 some changes
    [Apollo - DSP.kicad_pcb, DSP.kicad_sch]
2023-08-31 modifications for rev 3
    [Analog.kicad_sch, Apollo - DSP.kicad_pcb, Apollo - DSP.kicad_sch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]
2023-10-03 ready for order
    [Analog.kicad_sch, Apollo - DSP.kicad_pcb, Apollo - DSP.kicad_sch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]
2023-10-05 checking for possible mistakes
    [Apollo - DSP-B_Cu.gbr, Apollo - DSP-B_Mask.gbr, Apollo - DSP-B_Paste.gbr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]
2023-10-18 FIXED ADCVOLTAGE PIN
    [Apollo - DSP.kicad_pcb, DSP.kicad_sch]
2024-02-19 refreshing design
    [Apollo - DSP.kicad_pcb, DSP.kicad_sch]
2026-05-26 remove tracked build artifacts, backups, and IDE metadata; update .gitignore
    Drop Debug/, Release/, .metadata/, .settings/, backup ZIPs, KiCad local
    state files, and the orphaned Memory.kicad_sch sub-schematic. Update
    .gitignore to prevent these from being re-added. Add CLAUDE.md project
    instructions.
    [Memory.kicad_sch]
2026-05-26 replace monolithic firmware with modular architecture
    Remove old single-file drivers (23K256, MCP4726, filter, microprint,
    SDCARD) and replace with layered modules: app/, drivers/, dsp/, and
    platform/. main.c now delegates to apollo_app_init/apollo_app_task.
    USB CDC receive callback routes through apollo_usb_cdc.
    No firmware behavior change: the default signal path (ADC CH0, 1 kHz
    low-pass, DAC output, SRAM logging, USB telemetry) is preserved.
    [apollo_adc.c, apollo_app.c, apollo_config.h]
2026-05-26 add documentation, host tests, and CI workflow
    Add docs/ with architecture, hardware, firmware, DSP filter, demo,
    testing, case study, and future work notes. Add tests/host/test_runner.c
    for host-buildable logic tests (DSP filters, command parsing, telemetry,
    diagnostics, signal chain). Add GitHub Actions CI workflow targeting
    Ubuntu host tests. Add REPOSITORY_STRUCTURE.md index.
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2026-05-26 record verified firmware Debug and Release build results
    Both configurations build with 0 errors using STM32CubeIDE 2.0.0
    headless builder and arm-none-eabi-gcc 14.3.1. Debug: 75 KB text,
    Release: 50 KB text — well within 128 KB flash.
    Phase 3 now partial: firmware builds; remaining items require
    physical board for USB CDC, ADC, DAC, and SRAM validation.
2026-05-26 add DMA as compile-time selectable ADC acquisition mode
    Define APOLLO_ADC_USE_DMA=1 to switch from blocking polling to
    DMA-based acquisition. DMA completion callback records samples
    and tracks overruns, missed samples, and DMA errors via
    apollo_adc_get_stats(). Polling remains the default.
    Both paths verified: CubeIDE Debug build (polling) and cross-compile
    (DMA) pass with 0 errors. API is unchanged so apollo_app does not
    depend on the acquisition mode.
    Phase 6: ADC timer/DMA.
    [apollo_adc.c]
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

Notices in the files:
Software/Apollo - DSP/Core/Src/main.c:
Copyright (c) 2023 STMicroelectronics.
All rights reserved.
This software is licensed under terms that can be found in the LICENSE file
